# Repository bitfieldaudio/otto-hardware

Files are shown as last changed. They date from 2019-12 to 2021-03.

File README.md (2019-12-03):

# Description
otto-hw-beta is the hardware design for the OTTO beta circuit board. The design is implemented in KiCad.

# Target Outputs
By Beta formal release, the target output files will be the following:
Schematic
Layout
Fabrication Gerber
	Copper Layers
	Soldermask
	Silkscreen
	Drill
Assembly Gerber
	Paste Mask
	Component/Pin-XY Data
Bill of Materials
	Installed/Not-Installed
	Part Numbers
	Purchase Reference links
	Est. Cost

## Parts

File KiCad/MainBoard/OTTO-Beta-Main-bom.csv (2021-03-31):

Comment | Designator | Footprint | LCSC | JLCASM | MPN | LCSC PN
4.7uF | C211 | Capacitor_SMD:C_0805_2012Metric_Pad1.15x1.40mm_HandSolder |  | BASIC | CL21A475KAQNNNE | C1779
1uF | C219,C218 | Capacitor_SMD:C_0805_2012Metric_Pad1.15x1.40mm_HandSolder |  | BASIC | CL21B105KBFNNNE | C28323
2.2uF | C221,C222 | Capacitor_SMD:C_0805_2012Metric_Pad1.15x1.40mm_HandSolder |  | BASIC | 0805F225M500NT | C49217
10uF | C246,C250,C264,C247,C243,C261,C260,C3,C1 | Capacitor_SMD:C_0805_2012Metric_Pad1.15x1.40mm_HandSolder |  | BASIC | CL21A106KAYNNNE | C15850
1uF (AUDIO) | C254,C251,C253,C255,C257 | OTTO_Footprints_Lib:C_Rect_L7.2mm_W5.0mm_P5.00mm_FKS2_FKP2_MKS2_MKP2 |  | DNP | MKS2C041001F00JSSD | C92673
220pF (C0G) | C256,C252,C259 | Capacitor_SMD:C_0805_2012Metric_Pad1.15x1.40mm_HandSolder |  | BASIC | CL21B221KBANNNC | C53172
220uF | C262,C258,C84,C81,C79 | OTTO_Footprints_Lib:CP_Elec_6.3x4.5 |  | EXT | OVZ221M0JTR-0604 | C250096
30pF | C265,C266,C205,C204 | Capacitor_SMD:C_0805_2012Metric_Pad1.15x1.40mm_HandSolder |  | BASIC | CL21C300JBANNNC | C1809
10uf Tantalum | C268,C267 | OTTO_Footprints_Lib:CP_EIA-3216-18_Kemet-A_Pad1.58x1.35mm_HandSolder |  | BASIC | TAJA106K016RNJ | C7171
100nF | C72,C73,C74,C71,C70,C69,C68,C98,C49,C50,C51,C52,C55,C48,C53,C54,C56,C60,C61,C62,C63,C64,C65,C66,C67,C7,C4 | Capacitor_SMD:C_0805_2012Metric_Pad1.15x1.40mm_HandSolder |  | BASIC | CC0805KRX7R9BB104 | C49678
1nF | C8 | Capacitor_SMD:C_0805_2012Metric_Pad1.15x1.40mm_HandSolder |  | BASIC | CL21B102KBCNNNC | C46653
10nF | C87,C2,C5,C6 | Capacitor_SMD:C_0805_2012Metric_Pad1.15x1.40mm_HandSolder |  | BASIC | CL21B103KBANNNC | C1710
47uF | C9,C10,C11 | Capacitor_SMD:C_1206_3216Metric_Pad1.42x1.75mm_HandSolder |  | BASIC | CL31A476MPHNNNE | C96123
15pF | C96,C97 | Capacitor_SMD:C_0805_2012Metric_Pad1.15x1.40mm_HandSolder |  | BASIC | CL21C150JBANNNC | C1794
SM4007PL | D1,D3,D4,D5,D6,D7,D8,D9,D10,D11,D12,D13,D14,D15,D16,D17,D18,D19,D20,D21,D22,D23,D24,D25,D26,D27,D34,D41,D33,D47,D40,D32,D46,D39,D31,D45,D38,D30,D44,D37,D29,D43,D36,D28,D42,D35,D202,D204,D203,D205,D2,D58,D64,D63,D62,D61,D60,D59 | Diode_SMD:D_SOD-123F |  | BASIC | SM4007PL | C64898
1N4148W | D206 | Diode_SMD:D_SOD-123 |  | BASIC | 1N4148W | C81598
15V BI TVS | D48 | Diode_SMD:D_SOD-123F |  | EXT | SMF15CA | C123803
15V ZENER | D49 | Diode_SMD:D_SOD-123 |  | EXT | BZT52C15 | C173427
6V BI TVS | D51,D53,D56,D55,D52,D50 | Diode_SMD:D_SOD-123F |  | EXT | SMF6.0CA | C123791
RED LED | D57 | LED_SMD:LED_0603_1608Metric |  | BASIC | KT-0603R | C2286
SS34 | D65,D54 | Diode_SMD:D_SMA |  | BASIC | SS34 | C8678
Barrel Jack, 2.0mmID, 6.5mmOD | DC201 | OTTO_Footprints_Lib:BarrelJack_2.0mmID_6.5mmOD |  | DNP | DC-005 5.5-2.0MM | C16214
ALPS EC11E183440C | ENC1,ENC2,ENC3,ENC4 | OTTO_Footprints_Lib:ALPS_EC11 |  | DNP | EC11E183440C | C370986
Fiducial | FID1,FID2,FID3,FID4,FID5,FID7,FID8,FID9,FID10,FID11,FID6,FID12 | Fiducial:Fiducial_1mm_Mask2mm |  | N/A | N/A
Tooling Hole | H101,H102,H103 | OTTO_Footprints_Lib:JLC_TOOLING_HOLE |  | N/A | N/A
MountingHole | H203,H201,H204,H202,H205 | OTTO_Footprints_Lib:Mounting_Hole_M2.5_Loose_Fit |  | N/A | N/A
MountingHole_Pad | H4,H3,H1,H5,H2 | MountingHole:MountingHole_3.2mm_M3_Pad_Via |  | N/A | N/A
Conn_ARM_JTAG_SWD_10 | J1 | Connector_PinHeader_1.27mm:PinHeader_2x05_P1.27mm_Vertical_SMD |  | DNP | 20021111-00010T4LF | C239059
Conn_02x04 | J2 | Connector_PinHeader_2.54mm:PinHeader_2x04_P2.54mm_Vertical |  | N/A | N/A
Raspberry Pi Connector | J201 | OTTO_Footprints_Lib:Raspberry_Pi_A_FacingDown_TH |  | N/A | M20-7812045
Conn_02x06 | J206 | OTTO_Footprints_Lib:Harwin_M20-7810645_2x06_P2.54mm_Vertical_SolderHoles |  | N/A | M20-7810645
Conn_02x03 | J207 | OTTO_Footprints_Lib:Harwin_M20-7810345_2x03_P2.54mm_Vertical_SolderHoles |  | N/A | M20-7810345
Conn_02x05 | J3,J6,J5,J4 | Connector_PinHeader_2.54mm:PinHeader_2x05_P2.54mm_Vertical |  | DNP | N/A | C124355
Conn_01x20 | J7 | OTTO_Footprints_Lib:X10B25L20T_FPC_1x20-1MP_P1.00mm_Horizontal |  | DNP |  | C124357
Conn_01x03 | J9 | Connector_PinHeader_2.54mm:PinHeader_1x03_P2.54mm_Vertical |  | DNP |  | C225478
15uH | L1 | OTTO_Footprints_Lib:L_6.6x7.1 |  | EXTDNP | MWSA0603-150MT | C132136
6.8uH | L2 | Inductor_SMD:L_Sunlord_MWSA0518_5.4x5.2mm |  | EXTDNP | SLO0530H6R8MTT | C325965
Microphone | MK201 | OTTO_Footprints_Lib:INGHAi_GMI6050p |  | DNP | GMI6050P-42db | C233942
Net-Tie_2 | NT1 | OTTO_Footprints_Lib:NetTie-2_Pad5.0mm |  | N/A | N/A
AO4407A | Q1 | OTTO_Footprints_Lib:SOIC-8_3.9x4.9mm_P1.27mm |  | BASIC | AO4407A | C16072
2N7002 | Q2 | Package_TO_SOT_SMD:SOT-23 |  | BASIC | 2N7002 | C8545
12k | R10 | Resistor_SMD:R_0805_2012Metric_Pad1.15x1.40mm_HandSolder |  | BASIC | 0805W8F1202T5E | C17444
4.3k | R11 | Resistor_SMD:R_0805_2012Metric_Pad1.15x1.40mm_HandSolder |  | BASIC | 0805W8F4301T5E | C17667
180k | R12 | Resistor_SMD:R_0805_2012Metric_Pad1.15x1.40mm_HandSolder |  | BASIC | 0805W8F1803T5E | C17501
13k | R15 | Resistor_SMD:R_0805_2012Metric_Pad1.15x1.40mm_HandSolder |  | BASIC | 0805W8F1302T5E | C17455
2.2k | R202,R205,R206,R207 | Resistor_SMD:R_0805_2012Metric_Pad1.15x1.40mm_HandSolder |  | BASIC | 0805W8F2201T5E | C17520
10 | R212,R214 | Resistor_SMD:R_0805_2012Metric_Pad1.15x1.40mm_HandSolder |  | BASIC | 0805W8F100JT5E | C17415
270 | R216 | Resistor_SMD:R_0805_2012Metric_Pad1.15x1.40mm_HandSolder |  | BASIC | 0805W8F2700T5E | C17590
220 | R217 | Resistor_SMD:R_0805_2012Metric_Pad1.15x1.40mm_HandSolder |  | BASIC | 0805W8F2200T5E | C17557
47k | R221,R225,R229,R230,R228,R204,R203,R4 | Resistor_SMD:R_0805_2012Metric_Pad1.15x1.40mm_HandSolder |  | BASIC | 0805W8F4702T5E | C17713
5.1k | R222,R224,R218,R219 | Resistor_SMD:R_0805_2012Metric_Pad1.15x1.40mm_HandSolder |  | BASIC | 0805W8F5101T5E | C27834
100 | R223,R220 | Resistor_SMD:R_0805_2012Metric_Pad1.15x1.40mm_HandSolder |  | BASIC | 0805W8F1000T5E | C17408
680 | R226 | Resistor_SMD:R_0805_2012Metric_Pad1.15x1.40mm_HandSolder |  | BASIC | 0805W8F6800T5E | C17798
330 | R227,R28 | Resistor_SMD:R_0805_2012Metric_Pad1.15x1.40mm_HandSolder |  | BASIC | 0805W8F3300T5E | C17630
33 | R231,R232,R233,R234,R235,R236,R237,R238,R213,R215 | Resistor_SMD:R_0805_2012Metric_Pad1.15x1.40mm_HandSolder |  | BASIC | 0805W8F330JT5E | C17634
100k | R26,R13,R18,R20,R16 | Resistor_SMD:R_0805_2012Metric_Pad1.15x1.40mm_HandSolder |  | BASIC | 0805W8F1003T5E | C17407
0 | R3,R2,R1,R19,R17 | Resistor_SMD:R_0805_2012Metric_Pad1.15x1.40mm_HandSolder |  | BASIC | 0805W8F0000T5E | C17477
10k | R30,R29,R14 | Resistor_SMD:R_0805_2012Metric_Pad1.15x1.40mm_HandSolder |  | BASIC | 0805W8F1002T5E | C17414
30k | R5 | Resistor_SMD:R_0805_2012Metric_Pad1.15x1.40mm_HandSolder |  | BASIC | 0805W8F3002T5E | C17621
4.7K | R6,R7 | Resistor_SMD:R_0805_2012Metric_Pad1.15x1.40mm_HandSolder |  | BASIC | 0805W8F4701T5E | C17673
68k | R8 | Resistor_SMD:R_0805_2012Metric_Pad1.15x1.40mm_HandSolder |  | BASIC | 0805W8F6802T5E | C17801
3.3k | R9 | Resistor_SMD:R_0805_2012Metric_Pad1.15x1.40mm_HandSolder |  | BASIC | 0805W8F3301T5E | C26010
ALPS SKHC | SW1,SW2,SW3,SW4,SW5,SW6,SW7,SW8,SW9,SW10,SW11,SW12,SW13,SW14,SW15,SW16 | OTTO_Footprints_Lib:ALPS_SKHC_white |  | DNP | SKHCBGA010 | C139753
ALPS SKHC | SW17,SW18,SW19,SW20,SW21,SW22,SW23,SW24,SW25,SW26 | OTTO_Footprints_Lib:ALPS_SKHC_black |  | DNP | SKHCBGA010 | C139753
5.2x5.2x1.5mm | SW201 | OTTO_Footprints_Lib:SW_SPST_5.2x5.2x1.5mm |  | EXTDNP | TS-1187A-B-A-B | C318884
SW_DIP_x02 | SW202,SW48 | OTTO_Footprints_Lib:SW_DIP_SPSTx02_Slide_HRO_EP-02KS |  | DNP | EP-02KS | C129087
6x6x13mm | SW41,SW34,SW27,SW42,SW35,SW28,SW43,SW36,SW29,SW44,SW37,SW30,SW45,SW38,SW31,SW46,SW39,SW32,SW47,SW40,SW33,SW50,SW51,SW52,SW53,SW54,SW55,SW56 | OTTO_Footprints_Lib:6x6mm_Switch |  | DNP | K2-1102DP-S3SW-04 | C136674
SW_DPDT_x2 | SW49 | OTTO_Footprints_Lib:SSAC120100 |  | DNP | SSAC120100 | C202374
TestPoint | TP8,TP9,TP7,TP2,TP15,TP16,TP17,TP1,TP18 | TestPoint:TestPoint_THTPad_D1.0mm_Drill0.5mm |  | N/A | N/A
PJ-3930-8A | TRS205,TRS204,TRS206,TRS201,TRS202,TRS203 | OTTO_Footprints_Lib:3.5mm_jack_PJ-3930-8A |  | DNP | PJ-3930-8A | C145811
TPS5430DDA | U1 | OTTO_Footprints_Lib:TI_SO-PowerPAD-8_ThermalVias |  | BASIC | TPS5430DDAR | C9864
TPS54331DR | U2 | Package_SO:SOIC-8-1EP_3.9x4.9mm_P1.27mm_EP2.41x3.81mm_ThermalVias |  | BASIC | TPS54331DR | C9865
6N137 | U201 | Package_DIP:DIP-8_W8.89mm_SMDSocket_LongPads |  | BASIC | 6N137S1(TA) | C110020
STM32F407VGTx | U202 | OTTO_Footprints_Lib:LQFP-100_14x14mm_P0.5mm |  | BASIC | STM32F407VGT6 | C12345
SRV05-4 | U204 | OTTO_Footprints_Lib:SOT-23-6 |  | BASIC | SRV05-4-P-T7 | C85364
SN74HC14 | U205 | OTTO_Footprints_Lib:SOIC-14_3.9x8.7mm_P1.27mm |  | EXT | SN74HC14DR | C6820
WM8731 | U207 | OTTO_Footprints_Lib:SSOP-28_5.3x10.2mm_P0.65mm |  | EXT | WM8731SEDS/RV | C41511
AMS1117-3.3 | U208 | OTTO_Footprints_Lib:SOT-223-3_TabPin2 |  | BASIC | AMS1117-3.3 | C6186
TPS22918_SOT23-6_A | U5 | OTTO_Footprints_Lib:SOT-23-6 |  | EXT | TPS22918DBVR | C134020
USB_B | USB201 | OTTO_Footprints_Lib:USB_B |  | DNP | 292304-1 | C86462
25MHz | Y201 | Crystal:Crystal_SMD_3225-4Pin_3.2x2.5mm |  | EXT | X322525MOB4SI | C9006
32.768kHz | Y202 | OTTO_Footprints_Lib:Crystal_SMD_3215-2Pin_3.2x1.5mm_HandSoldering |  | EXT | Q13FC1350000400 | C32346
12.288MHz | Y203 | Crystal:Crystal_SMD_3225-4Pin_3.2x2.5mm |  | EXT | X322512288MOB4SC | C70567

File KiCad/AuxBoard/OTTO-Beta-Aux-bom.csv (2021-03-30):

Comment | Designator | Footprint | LCSC | AssemblyOption | JLCASM | MPN | LCSC PN
100nF | C16,C15,C14,C13,C12,C11,C10,C9,C8,C7,C6,C5,C4,C3,C2,C1,C26,C25,C24,C23,C22,C21,C20,C19,C18,C17,C29,C30,C28,C33,C31,C32,C34,C46,C45,C47,C42,C41,C44,C43,C39,C38,C40,C35,C37,C36,C27,C78,C105,C104,C103,C102,C101,C100,C99 | Capacitor_SMD:C_0805_2012Metric |  |  | BASIC | CC0805KRX7R9BB104 | C49678
100nF | C48 | Capacitor_SMD:C_0805_2012Metric_Pad1.15x1.40mm_HandSolder |  |  | BASIC | CC0805KRX7R9BB104 | C49678
ALPS EC11 HOLE | ENC1,ENC2,ENC4,ENC3 | OTTO_Footprints_Lib:ALPS_EC11_aux_hole |  |  | N/A | N/A
Fiducial | FID1,FID2,FID3,FID4,FID5,FID7,FID8,FID9,FID10,FID11,FID6,FID12 | Fiducial:Fiducial_1mm_Mask2mm |  | DNP | N/A | N/A
Tooling Hole | H101,H102,H103 | OTTO_Footprints_Lib:JLC_TOOLING_HOLE |  | DNP | N/A | N/A
MountingHole | H201,H203,H205,H204,H202 | OTTO_Footprints_Lib:Mounting_Hole_M2.5_Loose_Fit |  | DNP | N/A | N/A
MountingHole_Pad | H5,H2,H1,H3,H4 | OTTO_Footprints_Lib:MountingHoleHole |  | DNP | N/A | N/A
Conn_01x20 | J1 | OTTO_Footprints_Lib:X10B25L20T_FPC_1x20-1MP_P1.00mm_Horizontal |  |  | DNP | X10B25L20T | C500179
Conn_02x25_Counter_Clockwise | J1_KD028QVFMA17 | OTTO_Footprints_Lib:F0501-B-50-20T-R |  |  | DNP | F0501-B-50-20T-R | C481235
WS2812C | LED47,LED46,LED45,LED44,LED41,LED42,LED43,LED35,LED34,LED36,LED39,LED38,LED37,LED40,LED27,LED33,LED32,LED31,LED30,LED29,LED28,LED17,LED18,LED19,LED20,LED21,LED22,LED23,LED24,LED25,LED26,LED12,LED11,LED10,LED9,LED16,LED15,LED14,LED13,LED7,LED6,LED5,LED4,LED3,LED2,LED1,LED8,LED48,LED49,LED50,LED51,LED52,LED53,LED54 | OTTO_Footprints_Lib:LED_WS2812B_PLCC4_5.0x5.0mm_P3.2mm |  |  | EXT | WS2812C | C114587
AO3400A | Q1 | OTTO_Footprints_Lib:SOT-23 |  |  | BASIC | AO3400A | C20917
47k | R1 | Resistor_SMD:R_0805_2012Metric_Pad1.15x1.40mm_HandSolder |  |  | BASIC | 0805W8F4702T5E | C17713
100k | R11 | Resistor_SMD:R_0805_2012Metric_Pad1.15x1.40mm_HandSolder |  |  | BASIC | 0805W8F1003T5E | C17407
90 | R2,R9,R8,R7,R6,R5 | Resistor_SMD:R_0805_2012Metric_Pad1.15x1.40mm_HandSolder |  |  | EXT | 0805W8F900JT5E | C247027
100 | R208 | Resistor_SMD:R_0805_2012Metric_Pad1.15x1.40mm_HandSolder |  |  | BASIC | 0805W8F1000T5E | C17408
ALPS SKHC Hole | SW17,SW1,SW18,SW19,SW20,SW21,SW2,SW22,SW23,SW24,SW25,SW26,SW3,SW4,SW5,SW6,SW7,SW8,SW9,SW10,SW11,SW12,SW13,SW14,SW15,SW16 | OTTO_Footprints_Lib:ALPS_SKHC_aux_hole |  |  | N/A
6x6x13mm Hole | SW41,SW34,SW27,SW42,SW35,SW28,SW43,SW36,SW29,SW44,SW37,SW30,SW45,SW38,SW31,SW46,SW39,SW32,SW47,SW40,SW33,SW50,SW51,SW52,SW53,SW54,SW55,SW56 | OTTO_Footprints_Lib:6x6mm_Switch_aux_hole |  |  | N/A
SN74LV1T34_SOT-23_A | U1 | OTTO_Footprints_Lib:SOT-23-5_HandSoldering |  |  | EXT | SN74LV1T34DBVR | C100024

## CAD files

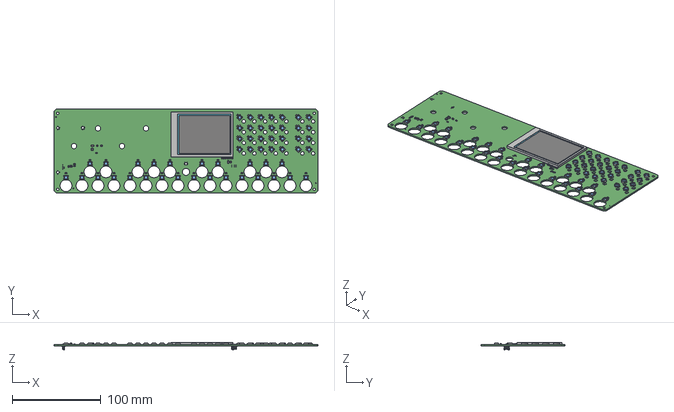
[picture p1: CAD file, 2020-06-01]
KicadFrontPanel/OTTO_FrontPanel_SMD.step
297.0 x 95.0 x 8.30 mm

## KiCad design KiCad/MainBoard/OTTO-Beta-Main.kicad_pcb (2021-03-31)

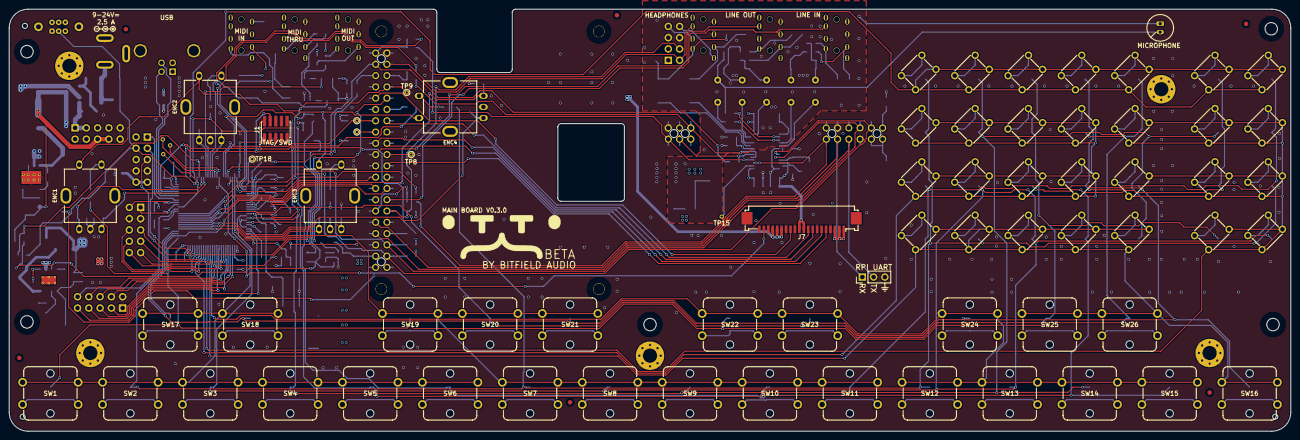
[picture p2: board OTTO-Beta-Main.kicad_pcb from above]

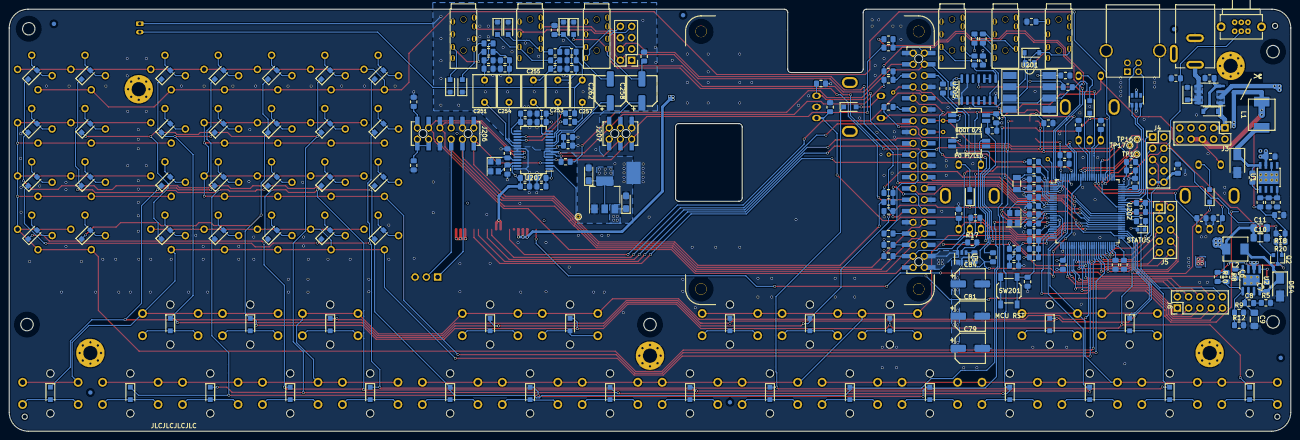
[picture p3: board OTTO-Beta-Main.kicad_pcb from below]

Board: 4 copper layers, 288.5 x 95.0 mm, 330 parts (244 on the bottom side), 223 nets.

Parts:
C1, C3, C243, C246, C247, C250, C260, C261, C264: 10uF; C_0805_2012Metric_Pad1.15x1.40mm_HandSolder
C2, C5, C6, C87: 10nF; C_0805_2012Metric_Pad1.15x1.40mm_HandSolder
C4, C7, C48, C49, C50, C51, C52, C53, C54, C55, C56, C60, C61, C62, C63, C64, C65, C66, C67, C68, C69, C70, C71, C72, C73, C74, C98: 100nF; C_0805_2012Metric_Pad1.15x1.40mm_HandSolder
C8: 1nF; C_0805_2012Metric_Pad1.15x1.40mm_HandSolder
C9, C10, C11: 47uF; C_1206_3216Metric_Pad1.42x1.75mm_HandSolder
C79, C81, C84, C258, C262: 220uF; CP_Elec_6.3x4.5
C96, C97: 15pF; C_0805_2012Metric_Pad1.15x1.40mm_HandSolder
C204, C205, C265, C266: 30pF; C_0805_2012Metric_Pad1.15x1.40mm_HandSolder
C211: 4.7uF; C_0805_2012Metric_Pad1.15x1.40mm_HandSolder
C218, C219: 1uF; C_0805_2012Metric_Pad1.15x1.40mm_HandSolder
C221, C222: 2.2uF; C_0805_2012Metric_Pad1.15x1.40mm_HandSolder
C251, C253, C254, C255, C257: 1uF (AUDIO); C_Rect_L7.2mm_W5.0mm_P5.00mm_FKS2_FKP2_MKS2_MKP2
C252, C256, C259: 220pF (C0G); C_0805_2012Metric_Pad1.15x1.40mm_HandSolder
C267, C268: 10uf Tantalum; CP_EIA-3216-18_Kemet-A_Pad1.58x1.35mm_HandSolder
D1, D2, D3, D4, D5, D6, D7, D8, D9, D10, D11, D12, D13, D14, D15, D16, D17, D18, D19, D20, D21, D22, D23, D24, D25, D26, D27, D28, D29, D30, D31, D32, D33, D34, D35, D36, D37, D38, D39, D40, D41, D42, D43, D44, D45, D46, D47, D58, D59, D60, D61, D62, D63, D64, D202, D203, D204, D205: SM4007PL; D_SOD-123F
D48: 15V BI TVS; D_SOD-123F
D49: 15V ZENER; D_SOD-123
D50, D51, D52, D53, D55, D56: 6V BI TVS; D_SOD-123F
D54, D65: SS34; D_SMA
D57: RED LED; LED_0603_1608Metric
D206: 1N4148W; D_SOD-123
DC201: Barrel Jack, 2.0mmID, 6.5mmOD; BarrelJack_2.0mmID_6.5mmOD
ENC1, ENC2, ENC3, ENC4: ALPS EC11E183440C; ALPS_EC11
FID1, FID2, FID3, FID4, FID5, FID6, FID7, FID8, FID9, FID10, FID11, FID12: Fiducial; Fiducial_1mm_Mask2mm
H1, H2, H3, H4, H5: MountingHole_Pad; MountingHole_3.2mm_M3_Pad_Via
H101, H102, H103: Tooling Hole; JLC_TOOLING_HOLE
H201, H202, H203, H204, H205: MountingHole; Mounting_Hole_M2.5_Loose_Fit
J1: Conn_ARM_JTAG_SWD_10; PinHeader_2x05_P1.27mm_Vertical_SMD
J2: Conn_02x04; PinHeader_2x04_P2.54mm_Vertical
J3, J4, J5, J6: Conn_02x05; PinHeader_2x05_P2.54mm_Vertical
J7: Conn_01x20; X10B25L20T_FPC_1x20-1MP_P1.00mm_Horizontal
J9: Conn_01x03; PinHeader_1x03_P2.54mm_Vertical
J201: Raspberry Pi Connector; Raspberry_Pi_A_FacingDown_TH
J206: Conn_02x06; Harwin_M20-7810645_2x06_P2.54mm_Vertical_SolderHoles
J207: Conn_02x03; Harwin_M20-7810345_2x03_P2.54mm_Vertical_SolderHoles
L1: 15uH; L_6.6x7.1
L2: 6.8uH; L_Sunlord_MWSA0518_5.4x5.2mm
MK201: Microphone; INGHAi_GMI6050p
NT1: Net-Tie_2; NetTie-2_Pad5.0mm
Q1: AO4407A; SOIC-8_3.9x4.9mm_P1.27mm
Q2: 2N7002; SOT-23
R1, R2, R3, R17, R19: 0; R_0805_2012Metric_Pad1.15x1.40mm_HandSolder
R4, R203, R204, R221, R225, R228, R229, R230: 47k; R_0805_2012Metric_Pad1.15x1.40mm_HandSolder
R5: 30k; R_0805_2012Metric_Pad1.15x1.40mm_HandSolder
R6, R7: 4.7K; R_0805_2012Metric_Pad1.15x1.40mm_HandSolder
R8: 68k; R_0805_2012Metric_Pad1.15x1.40mm_HandSolder
R9: 3.3k; R_0805_2012Metric_Pad1.15x1.40mm_HandSolder
R10: 12k; R_0805_2012Metric_Pad1.15x1.40mm_HandSolder
R11: 4.3k; R_0805_2012Metric_Pad1.15x1.40mm_HandSolder
R12: 180k; R_0805_2012Metric_Pad1.15x1.40mm_HandSolder
R13, R16, R18, R20, R26: 100k; R_0805_2012Metric_Pad1.15x1.40mm_HandSolder
R14, R29, R30: 10k; R_0805_2012Metric_Pad1.15x1.40mm_HandSolder
R15: 13k; R_0805_2012Metric_Pad1.15x1.40mm_HandSolder
R28, R227: 330; R_0805_2012Metric_Pad1.15x1.40mm_HandSolder
R202, R205, R206, R207: 2.2k; R_0805_2012Metric_Pad1.15x1.40mm_HandSolder
R212, R214: 10; R_0805_2012Metric_Pad1.15x1.40mm_HandSolder
R213, R215, R231, R232, R233, R234, R235, R236, R237, R238: 33; R_0805_2012Metric_Pad1.15x1.40mm_HandSolder
R216: 270; R_0805_2012Metric_Pad1.15x1.40mm_HandSolder
R217: 220; R_0805_2012Metric_Pad1.15x1.40mm_HandSolder
R218, R219, R222, R224: 5.1k; R_0805_2012Metric_Pad1.15x1.40mm_HandSolder
R220, R223: 100; R_0805_2012Metric_Pad1.15x1.40mm_HandSolder
R226: 680; R_0805_2012Metric_Pad1.15x1.40mm_HandSolder
SW1, SW2, SW3, SW4, SW5, SW6, SW7, SW8, SW9, SW10, SW11, SW12, SW13, SW14, SW15, SW16: ALPS SKHC; ALPS_SKHC_white
SW17, SW18, SW19, SW20, SW21, SW22, SW23, SW24, SW25, SW26: ALPS SKHC; ALPS_SKHC_black
SW27, SW28, SW29, SW30, SW31, SW32, SW33, SW34, SW35, SW36, SW37, SW38, SW39, SW40, SW41, SW42, SW43, SW44, SW45, SW46, SW47, SW50, SW51, SW52, SW53, SW54, SW55, SW56: 6x6x13mm; 6x6mm_Switch
SW48, SW202: SW_DIP_x02; SW_DIP_SPSTx02_Slide_HRO_EP-02KS
SW49: SW_DPDT_x2; SSAC120100
SW201: 5.2x5.2x1.5mm; SW_SPST_5.2x5.2x1.5mm
TP1, TP2, TP7, TP8, TP9, TP15, TP16, TP17, TP18: TestPoint; TestPoint_THTPad_D1.0mm_Drill0.5mm
TRS201, TRS202, TRS203, TRS204, TRS205, TRS206: PJ-3930-8A; 3.5mm_jack_PJ-3930-8A
U1: TPS5430DDA; TI_SO-PowerPAD-8_ThermalVias
U2: TPS54331DR; SOIC-8-1EP_3.9x4.9mm_P1.27mm_EP2.41x3.81mm_ThermalVias
U5: TPS22918_SOT23-6_A; SOT-23-6
U201: 6N137; DIP-8_W8.89mm_SMDSocket_LongPads
U202: STM32F407VGTx; LQFP-100_14x14mm_P0.5mm
U204: SRV05-4; SOT-23-6
U205: SN74HC14; SOIC-14_3.9x8.7mm_P1.27mm
U207: WM8731; SSOP-28_5.3x10.2mm_P0.65mm
U208: AMS1117-3.3; SOT-223-3_TabPin2
USB201: USB_B
Y201: 25MHz; Crystal_SMD_3225-4Pin_3.2x2.5mm
Y202: 32.768kHz; Crystal_SMD_3215-2Pin_3.2x1.5mm_HandSoldering
Y203: 12.288MHz; Crystal_SMD_3225-4Pin_3.2x2.5mm

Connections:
(F427)_SAI1_FS_A: R236.2, U202.3
(F427)_SAI1_MCLK_A: TP18.1, U202.1
(F427)_SAI1_SCK_A: R235.2, U202.4
(F427)_SAI1_SD_A: R237.2, U202.5
(F427)_SAI1_SD_B: R238.2, U202.2
+3V3A_MCU: C55.1, C219.1, R19.1, U202.21, U202.22
+3V3_ANALOG: C72.1, C73.1, C246.2, C250.2, C268.1, U207.8, U207.14, U208.2
+3V3_MCU: C3.2, C10.1, C11.1, C49.1, C50.1, C51.1, C52.1, C53.1, C54.1, C211.1, C218.2, D57.2, J1.1, J4.9, J4.10, L2.2, R4.1, R6.1, R8.1, R10.1, R19.2, R206.2, R207.1, SW202.1, SW202.2, U202.6, U202.11, U202.19, U202.28, U202.50, U202.75, U202.100
+3V3_RASPI: C69.2, C70.1, C71.2, C243.2, C247.1, C260.2, J7.10, J7.11, J201.1, J201.17, J206.1, R30.1, R202.1, R205.1, R213.1, R215.1, R216.1, U205.14, U207.1, U207.27
+5V_RASPI: C68.2, C261.2, C267.1, J7.1, J7.2, J7.3, J7.15, J7.16, J7.17, J201.2, J201.4, J206.2, J206.4, R17.1, U5.6, U201.8, U208.3
+5V_REG: C5.1, C79.1, C81.1, C84.1, J2.1, J2.3, J3.5, J3.6, J3.7, J3.8, L1.2, R14.1, R18.1, R20.1, SW48.1, U2.2, U5.1
/AUDIO/AMP_OUT_L: J2.8, TRS206.TS
/AUDIO/AMP_OUT_R: J2.7, TRS206.R1S
/AUDIO/CODEC_CLKOUT: TP15.1, U207.2
/AUDIO/HP_OUT_L: C258.2, D56.2, R228.2, TRS206.T
/AUDIO/HP_OUT_R: C262.2, D55.2, R230.2, TRS206.R1
/AUDIO/I2S_BCLK*: J206.12, R231.2, U207.3
/AUDIO/I2S_DIN*: J207.4, R233.2, U207.6
/AUDIO/I2S_DOUT*: J207.6, R234.2, U207.4
/AUDIO/I2S_LRCLK*: J207.1, R232.2, U207.5, U207.7
/AUDIO/LINE_IN_L: D51.2, R218.2, TRS204.T
/AUDIO/LINE_IN_R: D50.2, R222.2, TRS204.R1
/AUDIO/LINE_OUT_L: D53.2, R220.2, TRS205.T
/AUDIO/LINE_OUT_R: D52.2, R223.2, TRS205.R1
/AUDIO/MIC_IN: C257.2, C259.1, MK201.2, R226.2, R229.2
/CE1_GPIO7_RASPI: J201.26, TP2.1
/GPIO1_RASPI: J201.28, TP7.1, U202.93
/ICP_RST: C48.2, J1.10, R3.1, R4.2, SW201.1, U202.14
/ICP_SWCLK: J1.4, R2.1, R7.1, U202.76
/ICP_SWDIO: J1.2, R1.2, R6.2, U202.72
/MCU/3V3_RASPI_DIV_2: C56.2, R29.1, R30.2, U202.25
/MCU/+5V_USB: J4.1, J4.2, U202.68, U204.5, USB201.1
/MCU/BARREL_IN: C1.2, D49.1, J3.1, J3.2, J3.3, J3.4, Q1.1, Q1.2, Q1.3, U1.7
/MCU/BOOT0: R203.2, SW202.4, U202.94
/MCU/BOOT1: R204.2, SW202.3, U202.37
/MCU/COL_1: SW1.2, SW2.2, SW3.2, SW4.2, SW5.2, SW6.2, SW17.2, SW18.2, U202.97
/MCU/COL_2: SW7.2, SW8.2, SW9.2, SW10.2, SW11.2, SW19.2, SW20.2, SW21.2, U202.98
/MCU/COL_3: SW12.2, SW13.2, SW14.2, SW15.2, SW22.2, SW23.2, SW24.2, U202.38
/MCU/COL_4: SW16.2, SW25.2, SW26.2, SW27.2, SW28.2, SW29.2, SW30.2, SW31.2, U202.39
/MCU/COL_5: SW32.2, SW33.2, SW38.2, SW39.2, SW40.2, SW45.2, SW46.2, SW47.2, U202.41
/MCU/COL_6: SW34.2, SW35.2, SW36.2, SW37.2, SW41.2, SW42.2, SW43.2, SW44.2, U202.43
/MCU/COL_7: ENC1.S1, ENC2.S1, ENC3.S1, ENC4.S1, U202.46
/MCU/COL_8: SW50.2, SW51.2, SW52.2, SW53.2, SW54.2, SW55.2, SW56.2, U202.78
/MCU/CV_ADC_1: J6.5, U202.31
/MCU/CV_ADC_2: J6.6, U202.32
/MCU/CV_DAC_1: J6.3, U202.29
/MCU/CV_DAC_2: J6.4, U202.30
/MCU/ENC_A_1: C60.1, ENC1.A, U202.83
/MCU/ENC_A_2: C62.1, ENC2.A, U202.85
/MCU/ENC_A_3: C64.1, ENC3.A, U202.55
/MCU/ENC_A_4: C66.1, ENC4.A, U202.57
/MCU/ENC_B_1: C61.2, ENC1.B, U202.84
/MCU/ENC_B_2: C63.2, ENC2.B, U202.88
/MCU/ENC_B_3: C65.2, ENC3.B, U202.56
/MCU/ENC_B_4: C67.2, ENC4.B, U202.58
/MCU/EXP_GPIO_1_ADC: J5.9, U202.33
/MCU/EXP_GPIO_2_ADC: J5.10, U202.34
/MCU/EXP_GPIO_3_PWM: J5.7, U202.40
/MCU/EXP_GPIO_4_PWM: J5.8, U202.42
/MCU/EXP_GPIO_5_PWM: J5.5, U202.44
/MCU/EXP_GPIO_6_PWM: J5.6, U202.45
/MCU/GATE_IO_1: J6.7, U202.35
/MCU/GATE_IO_2: J6.8, U202.36
/MCU/I2C2_SCL: J5.2, R206.1, U202.67
/MCU/I2C2_SDA: J5.1, R207.2, U202.66
/MCU/MCU_PA0: J6.9, U202.23
/MCU/MCU_PC7: J6.10, U202.64
/MCU/MCU_PC8: TP1.1, U202.65
/MCU/OSC32_IN: C96.1, U202.8, Y202.2
/MCU/OSC32_OUT: C97.1, U202.9, Y202.1
/MCU/OSC_IN: C204.1, U202.12, Y201.3
/MCU/OSC_OUT: C205.1, U202.13, Y201.1
/MCU/PERIPHERALS/BARL: D48.1, DC201.1, Q1.5, Q1.6, Q1.7, Q1.8
/MCU/PERIPHERALS/PI_PWR_EN_OVERRIDE: R16.2, SW48.4
/MCU/PROG_UART_RX: J4.5, U202.48
/MCU/PROG_UART_TX: J4.3, U202.47
/MCU/ROW_1: D1.1, D19.1, D22.1, D25.1, D32.1, D43.1, D60.1, D202.1, U202.51
/MCU/ROW_2: D17.1, D20.1, D23.1, D26.1, D44.1, D45.1, D62.1, D203.1, U202.52
/MCU/ROW_3: D16.1, D18.1, D21.1, D24.1, D37.1, D38.1, D61.1, U202.53
/MCU/ROW_4: D2.1, D7.1, D12.1, D28.1, D40.1, D41.1, D58.1, D205.1, U202.54
/MCU/ROW_5: D3.1, D8.1, D13.1, D29.1, D33.1, D35.1, U202.15
/MCU/ROW_6: D4.1, D9.1, D14.1, D31.1, D42.1, D46.1, D59.1, U202.16
/MCU/ROW_7: D5.1, D10.1, D15.1, D30.1, D36.1, D39.1, D63.1, D204.1, U202.80
/MCU/ROW_8: D6.1, D11.1, D27.1, D34.1, D47.1, D64.1, U202.18
/MCU/SPI_MISO_MCU: TP17.1, U202.90
/MCU/SPI_SCLK_MCU: TP16.1, U202.89
/MCU/STATUS_LED: R28.1, U202.63
/MCU/USBD_N: U202.70, U204.3, USB201.2
/MCU/USBD_P: U202.71, U204.1, USB201.3
/PWM1_GPIO13_RASPI: J201.33, TP9.1, U202.62
/SPI_MISO_RASPI: J201.21, TP8.1
AMP_ENABLE: J2.4, J201.11, R26.1
BL_PWM: J7.13, J201.32
DISPLAY_RESET: J7.9, J201.27
GND: C1.1, C3.1, C4.2, C5.2, C6.2, C9.2, C10.2, C11.2, C48.1, C49.2, C50.2, C51.2, C52.2, C53.2, C54.2, C55.2, C56.1, C60.2, C61.1, C62.2, C63.1, C64.2, C65.1, C66.2, C67.1, C68.1, C69.1, C70.2, C71.1, C79.2, C81.2, C84.2, C87.2, C96.2, C97.2, C98.1, C204.2, C205.2, C211.2, C218.1, C219.2, C221.2, C222.2, C243.1, C247.2, C260.1, C261.1, C265.2, C266.2, D48.2, D54.2, D65.2, DC201.2, ENC1.C, ENC2.C, ENC3.C, ENC4.C, H1.1, H2.1, H3.1, H4.1, H5.1, J1.3, J1.5, J1.9, J3.9, J3.10, J4.7, J4.8, J5.3, J5.4, J6.1, J6.2, J7.4, J7.7, J7.12, J7.14, J7.18, J7.20, J9.3, J201.6, J201.9, J201.14, J201.20, J201.25, J201.30, J201.34, J201.39, J206.6, J206.9, J207.5, NT1.2, R5.2, R7.2, R9.2, R11.2, R12.2, R13.2, R15.2, R26.2, R29.2, R203.1, R204.1, SW49.1, SW201.2, TRS201.R2, TRS201.S, TRS202.R2, TRS202.S, U1.6, U1.9, U2.7, U5.2, U201.5, U202.10, U202.17, U202.20, U202.27, U202.74, U202.99, U204.2, U205.1, U205.7, U205.13, U207.21, U207.22, U207.28, USB201.4, USB201.5, Y201.2, Y201.4, Y203.2, Y203.4
GNDA: C72.2, C73.2, C74.2, C246.1, C250.1, C252.2, C256.2, C259.2, C264.1, C267.2, C268.2, D50.1, D51.1, D52.1, D53.1, D55.1, D56.1, J2.5, J2.6, MK201.1, NT1.1, R219.2, R221.1, R224.2, R225.1, R228.1, R229.1, R230.1, TRS204.R2, TRS204.S, TRS205.R2, TRS205.S, TRS206.R2, TRS206.S, U207.11, U207.15, U208.1
HP_SENSE: J2.2, J201.37, TRS206.R2S
I2C_SCL: J201.5, J206.5, R202.2, U202.95, U207.24
I2C_SDA: J201.3, J206.3, R205.2, U202.96, U207.23
I2S_BCLK: J201.12, R231.1, R235.1
I2S_DIN: J201.38, R233.1, R237.1
I2S_DOUT: J201.40, R234.1, R238.1
I2S_LRCLK: J201.35, R232.1, R236.1
LI_SENSE: J201.13, TRS204.R2S
LO_SENSE: J201.22, TRS205.R2S
MIDI_IN: R216.2, U201.6, U202.87, U205.3
MIDI_OUT: U202.86, U205.11
unnamed: C2.1, D65.1, L1.1, U1.8
unnamed: C2.2, U1.1
unnamed: C6.1, U2.4
unnamed: C7.1, D54.1, L2.1, U2.8
unnamed: C7.2, U2.1
unnamed: C8.1, C9.1, U2.6
unnamed: C8.2, R5.1
unnamed: C87.1, U5.4
unnamed: C98.2, TRS203.S
unnamed: C221.1, U202.49
unnamed: C222.1, U202.73
unnamed: C251.1, U207.20
unnamed: C251.2, C252.1, R218.1, R219.1
unnamed: C253.1, R220.1, R221.2
unnamed: C253.2, U207.12
unnamed: C254.1, U207.19
unnamed: C254.2, C256.1, R222.1, R224.1
unnamed: C255.1, R223.1, R225.2
unnamed: C255.2, U207.13
unnamed: C257.1, R227.2
unnamed: C258.1, U207.9
unnamed: C262.1, U207.10
unnamed: C74.1, C264.2, U207.16
unnamed: C265.1, U207.25, Y203.1
unnamed: C266.1, U207.26, Y203.3
unnamed: D1.2, SW1.1
unnamed: D2.2, SW2.1
unnamed: D3.2, SW3.1
unnamed: D4.2, SW4.1
unnamed: D5.2, SW5.1
unnamed: D6.2, SW6.1
unnamed: D7.2, SW7.1
unnamed: D8.2, SW8.1
unnamed: D9.2, SW9.1
unnamed: D10.2, SW10.1
unnamed: D11.2, SW11.1
unnamed: D12.2, SW12.1
unnamed: D13.2, SW13.1
unnamed: D14.2, SW14.1
unnamed: D15.2, SW15.1
unnamed: D16.2, SW16.1
unnamed: D17.2, SW17.1
unnamed: D18.2, SW18.1
unnamed: D19.2, SW19.1
unnamed: D20.2, SW20.1
unnamed: D21.2, SW21.1
unnamed: D22.2, SW22.1
unnamed: D23.2, SW23.1
unnamed: D24.2, SW24.1
unnamed: D25.2, SW25.1
unnamed: D26.2, SW26.1
unnamed: D27.2, SW27.1
unnamed: D28.2, SW28.1
unnamed: D29.2, SW29.1
unnamed: D30.2, SW30.1
unnamed: D31.2, SW31.1
unnamed: D32.2, SW32.1
unnamed: D33.2, SW33.1
unnamed: D34.2, SW34.1
unnamed: D35.2, SW35.1
unnamed: D36.2, SW36.1
unnamed: D37.2, SW37.1
unnamed: D38.2, SW38.1
unnamed: D39.2, SW39.1
unnamed: D40.2, SW40.1
unnamed: D41.2, SW41.1
unnamed: D42.2, SW42.1
unnamed: D43.2, SW43.1
unnamed: D44.2, SW44.1
unnamed: D45.2, SW45.1
unnamed: D46.2, SW46.1
unnamed: D47.2, SW47.1
unnamed: D49.2, Q1.4, R13.1
unnamed: D57.1, R28.2
unnamed: D58.2, SW50.1
unnamed: D59.2, SW51.1
unnamed: D60.2, SW52.1
unnamed: D61.2, SW53.1
unnamed: D62.2, SW54.1
unnamed: D63.2, SW55.1
unnamed: D64.2, SW56.1
unnamed: D202.2, ENC1.S2
unnamed: D203.2, ENC3.S2
unnamed: D204.2, ENC2.S2
unnamed: D205.2, ENC4.S2
unnamed: D206.1, R217.1, U201.2
unnamed: D206.2, TRS203.T, U201.3
unnamed: J201.7, R3.2
unnamed: J201.29, R1.1
unnamed: J201.36, R2.2
unnamed: R8.2, R9.1, R10.2, R12.1, U2.5
unnamed: R11.1, R14.2, R15.1, U1.4
unnamed: R17.2, U5.5
unnamed: R212.1, U205.8
unnamed: R212.2, TRS201.T
unnamed: R213.2, TRS201.R1
unnamed: R214.1, U205.6
unnamed: R214.2, TRS202.T
unnamed: R215.2, TRS202.R1
unnamed: R217.2, TRS203.R1
unnamed: R226.1, U207.17
unnamed: R227.1, U207.18
unnamed: U205.4, U205.5
unnamed: U205.9, U205.10
PI_PWR_EN: J201.31, Q2.3, R16.1, R20.2, U2.3, U5.3
PWR_BUTTON: C4.1, J4.4, Q2.2, SW49.2, U202.81
PWR_HOLD: Q2.1, R18.2, U202.82
RPI_UART_RX: J9.1, J201.10, J206.10
RPI_UART_TX: J9.2, J201.8, J206.8
SPI_CS_RASPI_DISPLAY: J7.8, J201.24
SPI_MOSI_MCU: J7.19, U202.91
SPI_MOSI_RASPI: J7.5, J201.19
SPI_SCLK_RASPI: J7.6, J201.23
TRIGGER1: J201.15, U202.59
TRIGGER2: J201.16, U202.60
TRIGGER3: J201.18, U202.61

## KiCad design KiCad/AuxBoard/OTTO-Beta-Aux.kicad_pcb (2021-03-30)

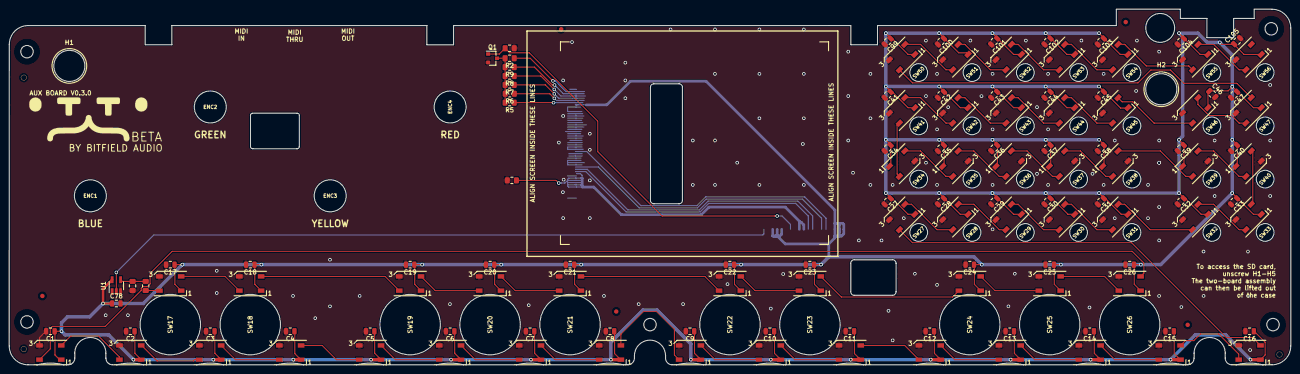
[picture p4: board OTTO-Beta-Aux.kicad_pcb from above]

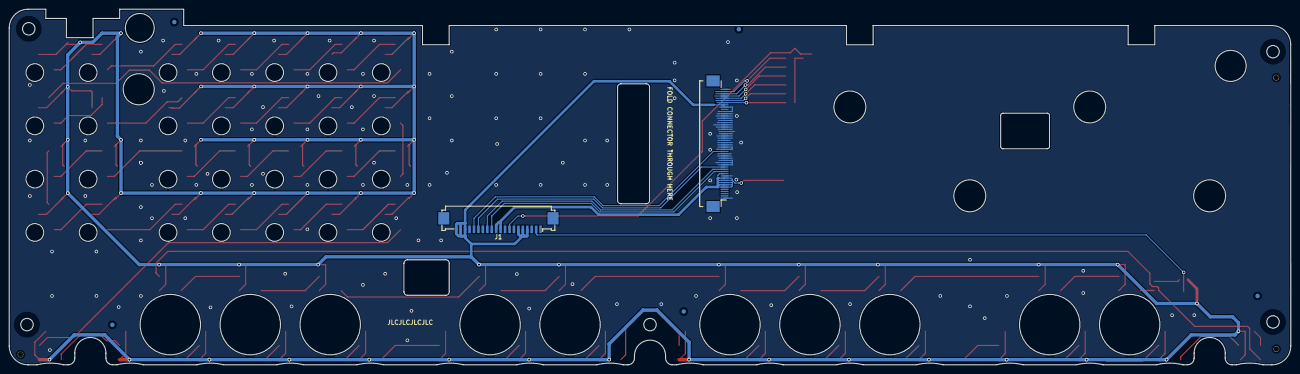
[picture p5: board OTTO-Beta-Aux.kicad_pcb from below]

Board: 2 copper layers, 288.5 x 80.1 mm, 185 parts (6 on the bottom side), 71 nets.

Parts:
C1, C2, C3, C4, C5, C6, C7, C8, C9, C10, C11, C12, C13, C14, C15, C16, C17, C18, C19, C20, C21, C22, C23, C24, C25, C26, C27, C28, C29, C30, C31, C32, C33, C34, C35, C36, C37, C38, C39, C40, C41, C42, C43, C44, C45, C46, C47, C78, C99, C100, C101, C102, C103, C104, C105: 100nF; C_0805_2012Metric
C48: 100nF; C_0805_2012Metric_Pad1.15x1.40mm_HandSolder
ENC1, ENC2, ENC3, ENC4: ALPS EC11 HOLE; ALPS_EC11_aux_hole
FID2, FID3, FID4, FID5, FID6, FID8, FID9, FID10, FID11, FID12: Fiducial; Fiducial_1mm_Mask2mm
H1, H2: MountingHole_Pad; MountingHoleHole
H101, H102, H103: Tooling Hole; JLC_TOOLING_HOLE
H201, H202, H203, H204, H205: MountingHole; Mounting_Hole_M2.5_Loose_Fit
J1: Conn_01x20; X10B25L20T_FPC_1x20-1MP_P1.00mm_Horizontal
J1_KD028QVFMA17: Conn_02x25_Counter_Clockwise; F0501-B-50-20T-R
LED1, LED2, LED3, LED4, LED5, LED6, LED7, LED8, LED9, LED10, LED11, LED12, LED13, LED14, LED15, LED16, LED17, LED18, LED19, LED20, LED21, LED22, LED23, LED24, LED25, LED26, LED27, LED28, LED29, LED30, LED31, LED32, LED33, LED34, LED35, LED36, LED37, LED38, LED39, LED40, LED41, LED42, LED43, LED44, LED45, LED46, LED47, LED48, LED49, LED50, LED51, LED52, LED53, LED54: WS2812C; LED_WS2812B_PLCC4_5.0x5.0mm_P3.2mm
Q1: AO3400A; SOT-23
R1: 47k; R_0805_2012Metric_Pad1.15x1.40mm_HandSolder
R2, R5, R6, R7, R8, R9: 90; R_0805_2012Metric_Pad1.15x1.40mm_HandSolder
R11: 100k; R_0805_2012Metric_Pad1.15x1.40mm_HandSolder
R208: 100; R_0805_2012Metric_Pad1.15x1.40mm_HandSolder
SW17, SW18, SW19, SW20, SW21, SW22, SW23, SW24, SW25, SW26: ALPS SKHC Hole; ALPS_SKHC_aux_hole
SW27, SW28, SW29, SW30, SW31, SW32, SW33, SW34, SW35, SW36, SW37, SW38, SW39, SW40, SW41, SW42, SW43, SW44, SW45, SW46, SW47, SW50, SW51, SW52, SW53, SW54, SW55, SW56: 6x6x13mm Hole; 6x6mm_Switch_aux_hole
U1: SN74LV1T34_SOT-23_A; SOT-23-5_HandSoldering

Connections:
3V3: C48.1, J1.10, J1.11, J1_KD028QVFMA17.6, J1_KD028QVFMA17.7, J1_KD028QVFMA17.8, J1_KD028QVFMA17.9, J1_KD028QVFMA17.10, J1_KD028QVFMA17.12
+5V: C1.1, C2.1, C3.1, C4.1, C5.1, C6.1, C7.1, C8.1, C9.1, C10.1, C11.1, C12.1, C13.1, C14.1, C15.1, C16.1, C17.1, C18.1, C19.1, C20.1, C21.1, C22.1, C23.1, C24.1, C25.1, C26.1, C27.1, C28.1, C29.1, C30.1, C31.1, C32.1, C33.1, C34.1, C35.1, C36.1, C37.1, C38.1, C39.1, C40.1, C41.1, C42.1, C43.1, C44.1, C45.1, C46.1, C47.1, C78.1, C99.1, C100.1, C101.1, C102.1, C103.1, C104.1, C105.1, J1.4, J1.5, J1.6, J1.18, J1.19, J1.20, J1_KD028QVFMA17.43, LED1.1, LED2.1, LED3.1, LED4.1, LED5.1, LED6.1, LED7.1, LED8.1, LED9.1, LED10.1, LED11.1, LED12.1, LED13.1, LED14.1, LED15.1, LED16.1, LED17.1, LED18.1, LED19.1, LED20.1, LED21.1, LED22.1, LED23.1, LED24.1, LED25.1, LED26.1, LED27.1, LED28.1, LED29.1, LED30.1, LED31.1, LED32.1, LED33.1, LED34.1, LED35.1, LED36.1, LED37.1, LED38.1, LED39.1, LED40.1, LED41.1, LED42.1, LED43.1, LED44.1, LED45.1, LED46.1, LED47.1, LED48.1, LED49.1, LED50.1, LED51.1, LED52.1, LED53.1, LED54.1, U1.5
/LEDs/LED_CONN1: LED1.4, LED26.2
/LEDs/LED_CONN2: LED16.2, LED27.4
/LEDs/LED_CONN3: LED47.2, LED48.4
/LEDs/LED_IN: LED17.4, R208.1
/LEDs/SPI_MOSI_MCU_5V: R11.1, R208.2, U1.4
/SPI_MOSI_MCU: J1.2, U1.2
BL_PWM: J1.8, Q1.1, R1.2
GND: C1.2, C2.2, C3.2, C4.2, C5.2, C6.2, C7.2, C8.2, C9.2, C10.2, C11.2, C12.2, C13.2, C14.2, C15.2, C16.2, C17.2, C18.2, C19.2, C20.2, C21.2, C22.2, C23.2, C24.2, C25.2, C26.2, C27.2, C28.2, C29.2, C30.2, C31.2, C32.2, C33.2, C34.2, C35.2, C36.2, C37.2, C38.2, C39.2, C40.2, C41.2, C42.2, C43.2, C44.2, C45.2, C46.2, C47.2, C48.2, C78.2, C99.2, C100.2, C101.2, C102.2, C103.2, C104.2, C105.2, J1.1, J1.3, J1.7, J1.9, J1.14, J1.17, J1_KD028QVFMA17.1, J1_KD028QVFMA17.11, J1_KD028QVFMA17.16, J1_KD028QVFMA17.17, J1_KD028QVFMA17.18, J1_KD028QVFMA17.19, J1_KD028QVFMA17.20, J1_KD028QVFMA17.21, J1_KD028QVFMA17.23, J1_KD028QVFMA17.24, J1_KD028QVFMA17.25, J1_KD028QVFMA17.26, J1_KD028QVFMA17.27, J1_KD028QVFMA17.28, J1_KD028QVFMA17.29, J1_KD028QVFMA17.30, J1_KD028QVFMA17.31, J1_KD028QVFMA17.32, J1_KD028QVFMA17.33, J1_KD028QVFMA17.34, J1_KD028QVFMA17.35, J1_KD028QVFMA17.36, J1_KD028QVFMA17.37, J1_KD028QVFMA17.38, J1_KD028QVFMA17.39, J1_KD028QVFMA17.40, J1_KD028QVFMA17.42, J1_KD028QVFMA17.50, LED1.3, LED2.3, LED3.3, LED4.3, LED5.3, LED6.3, LED7.3, LED8.3, LED9.3, LED10.3, LED11.3, LED12.3, LED13.3, LED14.3, LED15.3, LED16.3, LED17.3, LED18.3, LED19.3, LED20.3, LED21.3, LED22.3, LED23.3, LED24.3, LED25.3, LED26.3, LED27.3, LED28.3, LED29.3, LED30.3, LED31.3, LED32.3, LED33.3, LED34.3, LED35.3, LED36.3, LED37.3, LED38.3, LED39.3, LED40.3, LED41.3, LED42.3, LED43.3, LED44.3, LED45.3, LED46.3, LED47.3, LED48.3, LED49.3, LED50.3, LED51.3, LED52.3, LED53.3, LED54.3, Q1.2, R1.1, R11.2, U1.3
unnamed: J1_KD028QVFMA17.44, R5.1
unnamed: J1_KD028QVFMA17.45, R6.1
unnamed: J1_KD028QVFMA17.46, R7.1
unnamed: J1_KD028QVFMA17.47, R8.1
unnamed: J1_KD028QVFMA17.48, R9.1
unnamed: J1_KD028QVFMA17.49, R2.1
unnamed: LED1.2, LED2.4
unnamed: LED2.2, LED3.4
unnamed: LED3.2, LED4.4
unnamed: LED4.2, LED5.4
unnamed: LED5.2, LED6.4
unnamed: LED6.2, LED7.4
unnamed: LED7.2, LED8.4
unnamed: LED8.2, LED9.4
unnamed: LED10.2, LED11.4
unnamed: LED9.2, LED10.4
unnamed: LED11.2, LED12.4
unnamed: LED12.2, LED13.4
unnamed: LED13.2, LED14.4
unnamed: LED14.2, LED15.4
unnamed: LED15.2, LED16.4
unnamed: LED17.2, LED18.4
unnamed: LED18.2, LED19.4
unnamed: LED19.2, LED20.4
unnamed: LED20.2, LED21.4
unnamed: LED21.2, LED22.4
unnamed: LED22.2, LED23.4
unnamed: LED23.2, LED24.4
unnamed: LED24.2, LED25.4
unnamed: LED25.2, LED26.4
unnamed: LED27.2, LED28.4
unnamed: LED28.2, LED29.4
unnamed: LED29.2, LED30.4
unnamed: LED30.2, LED31.4
unnamed: LED31.2, LED32.4
unnamed: LED32.2, LED33.4
unnamed: LED33.2, LED40.4
unnamed: LED34.2, LED41.4
unnamed: LED34.4, LED35.2
unnamed: LED35.4, LED36.2
unnamed: LED36.4, LED37.2
unnamed: LED37.4, LED38.2
unnamed: LED38.4, LED39.2
unnamed: LED39.4, LED40.2
unnamed: LED41.2, LED42.4
unnamed: LED42.2, LED43.4
unnamed: LED43.2, LED44.4
unnamed: LED44.2, LED45.4
unnamed: LED45.2, LED46.4
unnamed: LED46.2, LED47.4
unnamed: LED48.2, LED49.4
unnamed: LED49.2, LED50.4
unnamed: LED50.2, LED51.4
unnamed: LED51.2, LED52.4
unnamed: LED52.2, LED53.4
unnamed: LED53.2, LED54.4
unnamed: Q1.3, R2.2, R5.2, R6.2, R7.2, R8.2, R9.2
RESET: J1.12, J1_KD028QVFMA17.13
SPI_CS_RASPI: J1.13, J1_KD028QVFMA17.14
SPI_MOSI_RASPI: J1.16, J1_KD028QVFMA17.22
SPI_SCLK_RASPI: J1.15, J1_KD028QVFMA17.15

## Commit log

2019-11-30 initial commit of schematic from Bastian
    [AUDIO.sch, KEYS+ENCODERS.sch, LEDS.sch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]
2019-11-30 add cached symbols to local library
    [AUDIO.sch, KEYS+ENCODERS.sch, LEDS.sch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]
2019-12-03 PWR entry, ESD, JTAG, PU/PDs modified. Review pass 1
    [AUDIO.sch, LEDS.sch, MCU.sch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]
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2019-12-10 roll in changes from Bastian
    [AUDIO.sch, KEYS+ENCODERS.sch, MCU.sch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]
2019-12-15 added buck/boost power supply for 5V rail
    [MCU.sch, PERIPHERALS.sch]
2019-12-31 added power switching and extra pulls for programming lines
    [AUDIO.sch, KEYS+ENCODERS.sch, LEDS.sch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]
2019-12-31 connected unconnected signals and MIDI to spare MCU UART
    [AUDIO.sch, LEDS.sch, MCU.sch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]
2020-01-02 add all resistor part numbers and create footprint library
    [AUDIO.sch, LEDS.sch, MCU.sch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]
2020-01-04 added part numbers for capacitors and crystals
    [AUDIO.sch, KEYS+ENCODERS.sch, LEDS.sch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]
2020-01-06 more part numbers added: audio caps
    [AUDIO.sch, MCU.sch, PERIPHERALS.sch]
2020-01-07 add more part numbers, samtec connector footprint
    [AUDIO.sch, KEYS+ENCODERS.sch, MCU.sch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]
2020-01-08 add switch and encoder parts. BM Complete. Footprints complete.
    [AUDIO.sch, KEYS+ENCODERS.sch, LEDS.sch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]
2020-01-10 add BOM scripts, fix schematic hierarchy
    [AUDIO.sch, KEYS+ENCODERS.sch, LEDS.sch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]
2020-01-11 Add power switch and other misc nice to haves
    [AUDIO.sch, KEYS+ENCODERS.sch, LEDS.sch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]
2020-01-11 Fixes for external battery board and Routing started
    [AUDIO.sch, MCU.sch, OTTOdiy_SMD.kicad_pcb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]
2020-01-11 Add SP3T style DP3T footprint and some schematic labels
    [AUDIO.sch, MCU.sch, MIDI.sch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]
2020-01-11 fix electrical rules check errors
    [MCU.sch, PERIPHERALS.sch]
2020-01-13 routed buck boost supply
    [AUDIO.sch, KEYS+ENCODERS.sch, LEDS.sch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]
2020-01-14 routed 3v3 and power switches
    [MCU.sch, OTTOdiy_SMD.kicad_pcb, PERIPHERALS.sch]
2020-01-18 add fault/status LED to MCU
    [MCU.sch, OTTOdiy_SMD.kicad_pcb]
2020-01-21 more power supply routing and stm32 placement
    [OTTOdiy_SMD.kicad_pcb]
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2020-01-24 fix peripheral connections and route more critical components
    [AUDIO.sch, MCU.sch, OTTOdiy_SMD.kicad_pcb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]
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2020-01-29 Placement of all components
    [MCU.sch, OTTOdiy_SMD.kicad_pcb, OTTOdiy_SMD.sch]
2020-01-30 change mcu reset button and route more stuff
    [MCU.sch, OTTOdiy_SMD.kicad_pcb, PERIPHERALS.sch]
2020-02-08 add analog ground layout
    [AUDIO.sch, MIDI.sch, OTTOdiy_SMD.kicad_pcb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]
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2020-02-19 started kay matrix routing
    [KEYS+ENCODERS.sch, OTTOdiy_SMD.kicad_pcb]
2020-02-19 key matrix routed (but untidy), added cutout for CPU heatsink
    [KEYS+ENCODERS.sch, OTTOdiy_SMD.kicad_pcb]
2020-02-20 Add and route 7 extra buttons/LEDs
    [KEYS+ENCODERS.sch, LEDS.sch, MCU.sch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]
2020-02-20 [wip] routing MCU expansion headers
    [OTTOdiy_SMD.kicad_pcb]
2020-02-21 More MCU connections routed
    [OTTOdiy_SMD.kicad_pcb]
2020-02-21 Even more MCU connections routed
    [OTTOdiy_SMD.kicad_pcb]
2020-02-23 Routed everything but power
    [OTTOdiy_SMD.kicad_pcb]
2020-02-25 swap 3.3V supply and 5v led switch. still needs reconnecting and cleanup
    [OTTOdiy_SMD.sch]
2020-02-25 cleaned up audio area, added board version pin
    [AUDIO.sch, MCU.sch]
2020-02-28 Added 3d models for encoders and switches
    [KEYS+ENCODERS.sch]
2020-02-29 more power plane cleanup, ARM 10 SWD connector modification for drill clearance
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2020-03-01 increase some clearances between planes and fix 10-pin samtec PN
    [AUDIO.sch, MCU.sch]
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2020-03-03 Remove headset microphone connection
    [AUDIO.sch]
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2020-03-24 Selected all LCSC parts. Check of part numbers complete
    [AUDIO.sch, KEYS+ENCODERS.sch, LEDS.sch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]
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2020-03-31 Fix DAC footprint and other minor issues.
    [AUDIO.sch, MCU.sch, MIDI.sch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]
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2020-05-25 Fix crystal symbols & Fix audio caps
    [AUDIO.sch, KEYS+ENCODERS.sch, LEDS.sch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]
2020-05-25 Fix jtag resistors
    [AUDIO.sch, MCU.sch, OTTOdiy_SMD.sch]
2020-05-27 [AUX] Expand SKHC footprints and move lower keys down
    [MCU.sch, OTTO_AUX_SMD.csv, OTTO_AUX_SMD.kicad_pcb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]
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2020-06-24 Add HEX spacers and fix AUX LED pinouts
    [AUDIO.sch, KEYS+ENCODERS.sch, LEDS.sch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]
2020-06-25 Replace inductors with larger part that is available at jlc
    [AUDIO.sch, MCU.sch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]
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2020-07-15 LEDs Rotated
    All LEDs have had their footprint and board orientation turned 180 degrees, to comply with assembly. Note that the 3rd pin has the marking on the physical part.
    [OTTO_AUX_SMD.kicad_pcb]
2020-07-15 Moved screen header
    Moved screen header to left side of screen.
    [OTTO_AUX_SMD.kicad_pcb, OTTOdiy_SMD.kicad_pcb]
2020-09-15 Cutouts for mounting frontplate
    Added cutouts to AUX board.
    Frontplate is now the correct size under the following assumptions:
    - 2mm space on left/right side of inner boards to box
    - 5 mm space as above on the front side. This is mainly to allow for insertion (the power switch sticks out)
    - no space on the back side
    [OTTO_AUX_SMD.kicad_pcb, OTTO_FrontPanel_SMD.kicad_pcb]
2020-10-17 Frontplate changes
    Changed icon placement and updated synth, loop, sequencer icons.
    Changed dimensions and added mounting brackets to the frontplate.
    [OTTO_AUX_SMD-2.step, OTTO_FrontPanel_SMD.kicad_pcb]
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2020-10-28 Revert "Add bracket step files"
    This reverts commit c21e747328c344bdd5d7dfb352835a19e2e00d67.
    [OTTO_AUX_SMD.kicad_pcb, OTTO_FrontPanel_SMD.kicad_pcb, OTTOdiy_SMD.kicad_pcb]
2020-10-31 Before 2 designs
    Fix paths for brackets.
    Before splitting into 2 designs for beta test.
    [OTTO_FrontPanel_SMD.kicad_pcb]
2020-11-01 Split to 2 frontplates
    Duplicated frontplate project
    Finished non-copper version
    [AUDIO.sch, KEYS+ENCODERS.sch, LEDS.sch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]
2020-11-01 Finished copper version
    Rebased copper version on finished non-copper version and finished copper version
    [OTTO_FrontPanel_SMD.kicad_pcb]
2020-11-01 Added JLCJLC... text
    Added JLC text to B.Silk for both frontplates
    [OTTO_FrontPanel_SMD.kicad_pcb]
2020-11-05 Changed relief logo
    Now the relief logo is actually a relief
    [OTTO_FrontPanel_SMD.kicad_pcb]
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2021-01-09 v0.3.0: various aux board fixes
    [OTTO_AUX_SMD.kicad_pcb]
2021-01-11 AUX: kbd key cutouts, screen cutout, H1-H5. Front plate: remove screw hole, mic rings footprint
    [OTTO_AUX_SMD.kicad_pcb, OTTO_FrontPanel_SMD.kicad_pcb]
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2021-02-28 WIP: routing of power management and new 3V3 IC
    [MCU.sch, OTTOdiy_SMD.kicad_pcb, PERIPHERALS.sch]
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2021-02-28 WIP: FPC connector, increase number of lanes. Main board routed
    [MCU.sch, OTTO_AUX_SMD.kicad_pcb, OTTO_AUX_SMD.sch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]
2021-03-05 FPC connector, increase number of lanes. AUX board routed
    [OTTO_AUX_SMD.kicad_pcb]
2021-03-22 Rotated SKHC switches to all be the same rotation
    [OTTOdiy_SMD.kicad_pcb]
2021-03-22 Fix board connection FPC connector rotation
    Also includes:
    - Slight cleanup of routing on both boards
    - Smaller holes for screws on aux board
    [AUDIO.sch, KEYS+ENCODERS.sch, MCU.sch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]
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2021-03-24 Restructure projects
    NOTE: Fixes very important bug, where a +5V_REG label in the power circuit
    was misspelled as 5V_REG. Just mentioning in case this commit is reverted
    [AUDIO.sch, KEYS+ENCODERS.sch, LEDS.sch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]
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2021-03-30 Aux v0.3.0
    Small adjustments to PCB outline
    switch to WS2812C LEDs
    [KEYS+ENCODERS.sch, LEDS.sch, OTTO-Beta-Aux.kicad_pcb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]
2021-03-30 Put LEDs on RPI power rail on aux board
    [LEDS.sch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]
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
